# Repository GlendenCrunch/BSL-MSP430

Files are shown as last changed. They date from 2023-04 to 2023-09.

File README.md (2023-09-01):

# BSL MSP430 + ftdi-rs232
+ Scheme and PCB of the adapter USB-FTDI to interface RS-232 and bootloader (BSL) for microcontrollers Texas Instrument MSP430
+ Libraries Eagle: SparkFun
+ For MAX232CPE from China capacitor С6 = 48 uF, otherwise it is not needed
+ Package 3D:

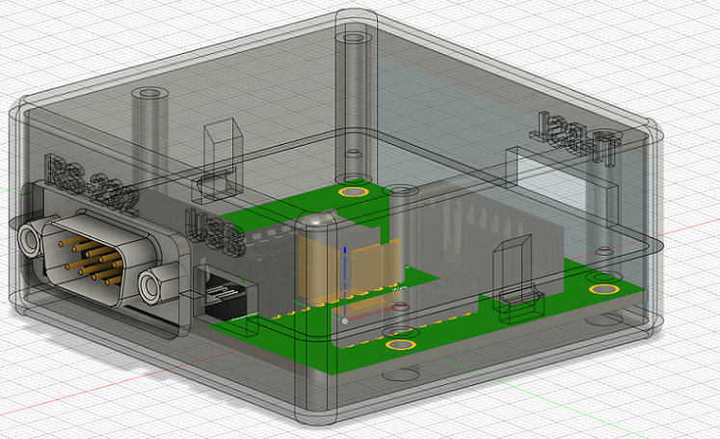
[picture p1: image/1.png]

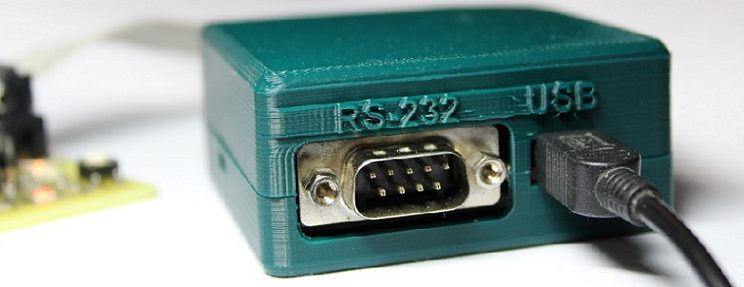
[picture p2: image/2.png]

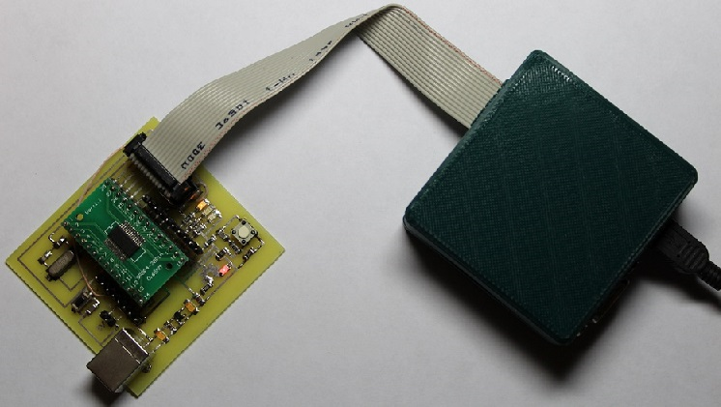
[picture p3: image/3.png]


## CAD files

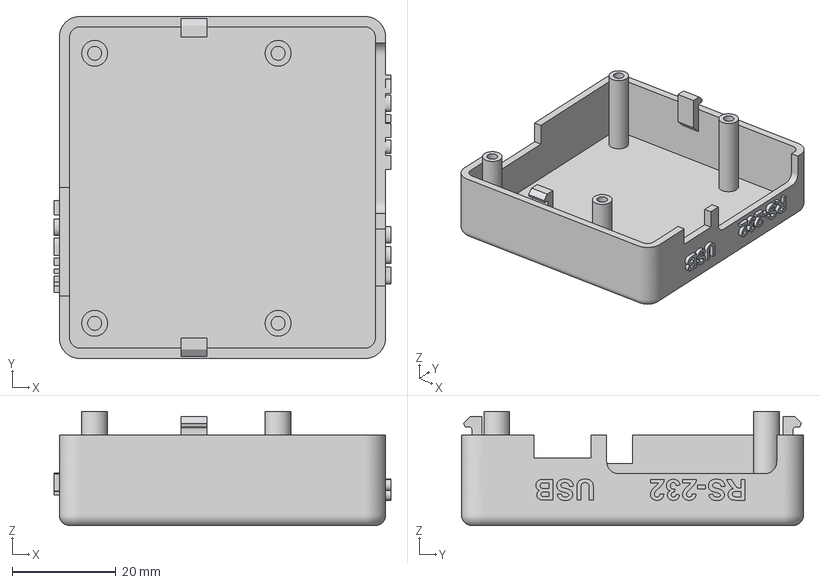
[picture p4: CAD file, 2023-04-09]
case_top.3mf
65.0 x 66.0 x 22.0 mm

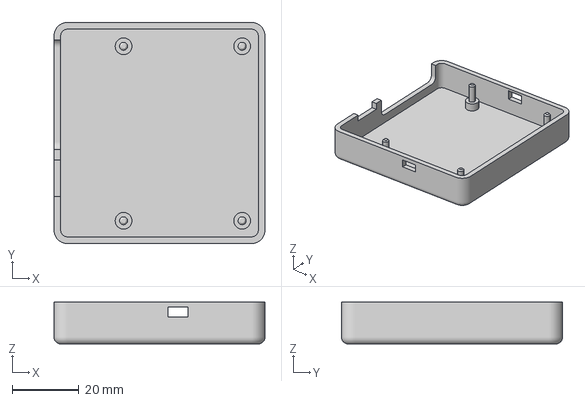
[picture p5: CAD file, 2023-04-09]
case_bottom.3mf
63.0 x 66.0 x 12.5 mm

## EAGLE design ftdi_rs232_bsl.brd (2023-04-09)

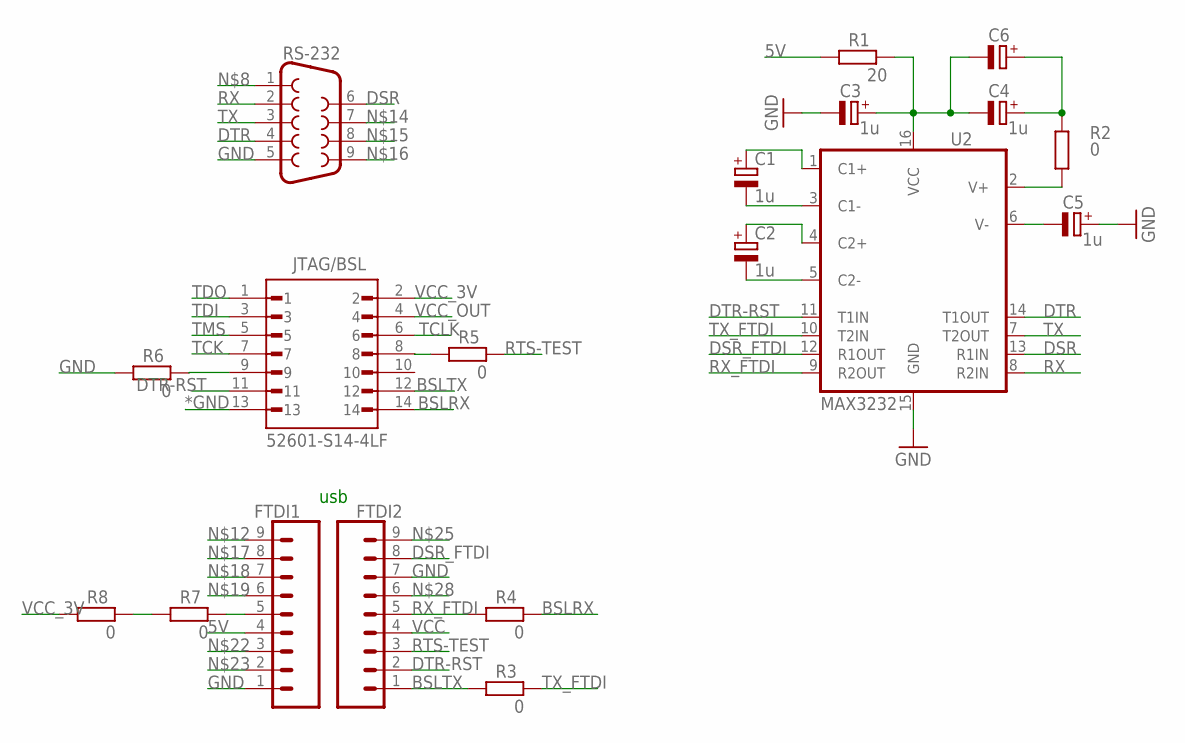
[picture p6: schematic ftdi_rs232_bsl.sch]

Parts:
C1, C2, C3, C4, C5: 1u; B/3528-21W
C6: CPOL-EUB/3528-21W; B/3528-21W
FTDI1, FTDI2: CONN_09NO_SILK; 1X09_NO_SILK
JTAG/BSL: 52601-S14-4LF; AMPHENOL_52601-S14-4LF
R1: 20; R1206
R2, R3, R4, R5, R6, R7, R8: 0; R1206
RS-232: DB9MALE; DB9_MALE
U2: MAX3232; DIP16

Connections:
5V: FTDI1.4, R1.1
*GND: JTAG/BSL.13
BSLRX: JTAG/BSL.14, R4.2
BSLTX: FTDI2.1, JTAG/BSL.12, R3.1
DSR: RS-232.6, U2.13 (R1IN)
DSR_FTDI: FTDI2.8, U2.12 (R1OUT)
DTR: RS-232.4, U2.14 (T1OUT)
DTR-RST: FTDI2.2, JTAG/BSL.11, U2.11 (T1IN)
GND: C3.-, C5.+, FTDI1.1, FTDI2.7, R6.1, RS-232.5, U2.15 (GND)
unnamed: C1.-, U2.3 (C1-)
unnamed: C2.-, U2.5 (C2-)
unnamed: C1.+, U2.1 (C1+)
unnamed: C2.+, U2.4 (C2+)
unnamed: C3.+, C4.-, C6.-, R1.2, U2.16 (VCC)
unnamed: C5.-, U2.6 (V-)
unnamed: C4.+, C6.+, R2.2
unnamed: R2.1, U2.2 (V+)
unnamed: JTAG/BSL.8, R5.1
unnamed: JTAG/BSL.9, R6.2
unnamed: FTDI1.5, R7.2
unnamed: R7.1, R8.2
RTS-TEST: FTDI2.3, R5.2
RX: RS-232.2, U2.8 (R2IN)
RX_FTDI: FTDI2.5, R4.1, U2.9 (R2OUT)
TCK: JTAG/BSL.7
TCLK: JTAG/BSL.6
TDI: JTAG/BSL.3
TDO: JTAG/BSL.1
TMS: JTAG/BSL.5
TX: RS-232.3, U2.7 (T2OUT)
TX_FTDI: R3.2, U2.10 (T2IN)
VCC: FTDI2.4
VCC_3V: JTAG/BSL.2, R8.1
VCC_OUT: JTAG/BSL.4

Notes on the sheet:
usb

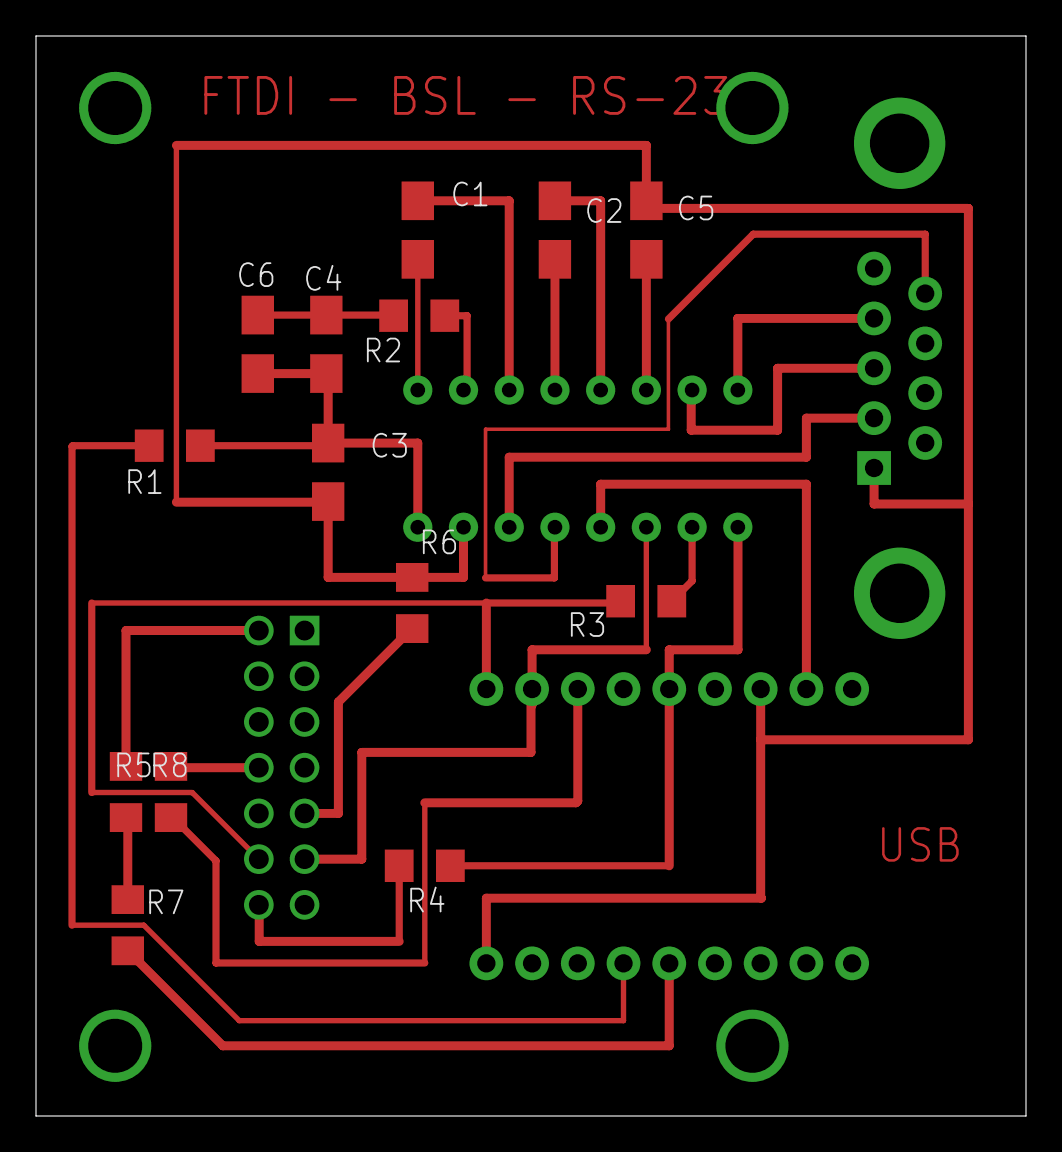
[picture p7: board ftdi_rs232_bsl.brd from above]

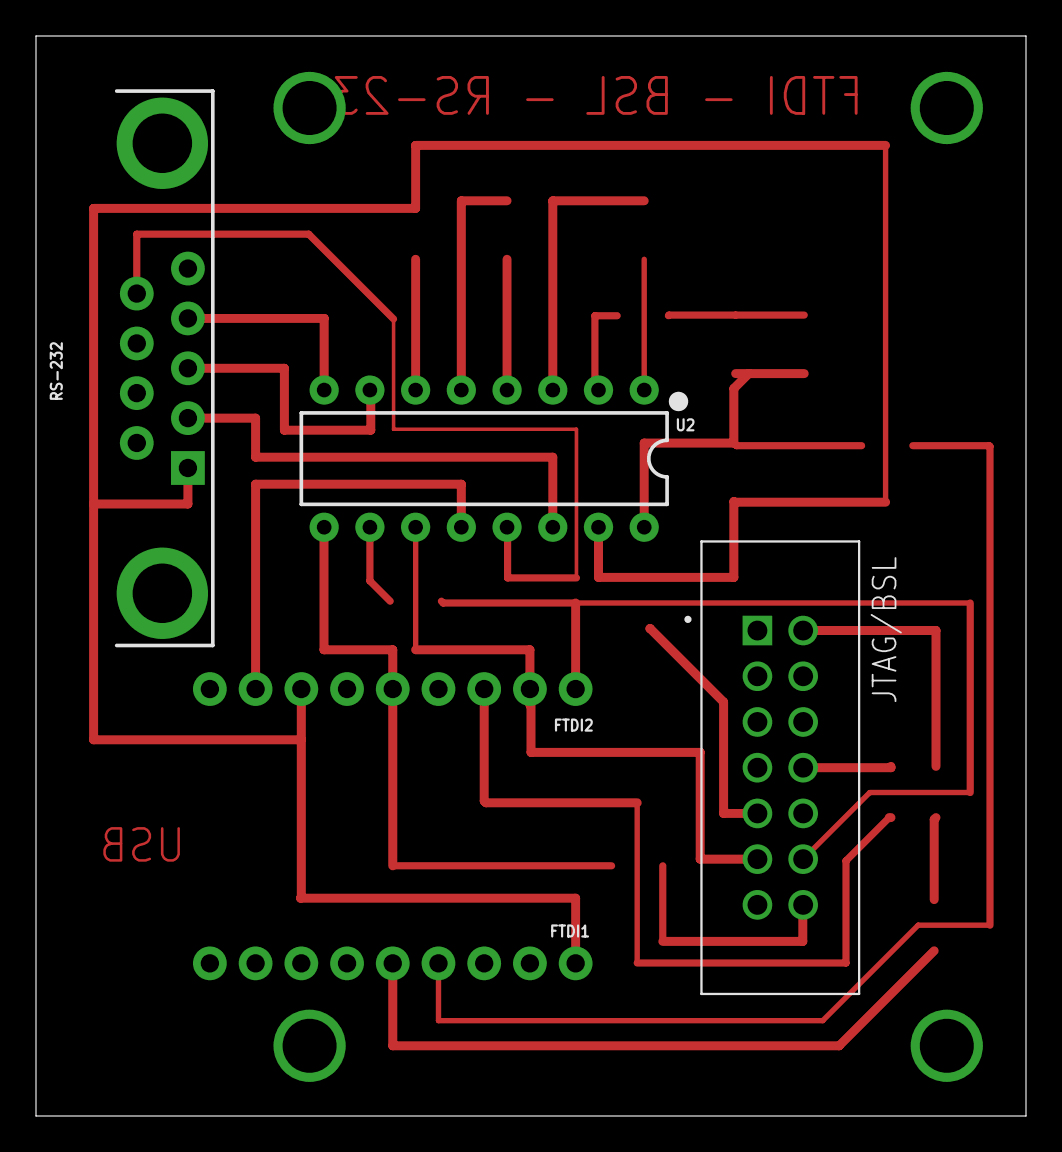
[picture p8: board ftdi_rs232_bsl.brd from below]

Board: 2 copper layers, 55.0 x 60.0 mm, 19 parts (5 on the bottom side), 26 nets.

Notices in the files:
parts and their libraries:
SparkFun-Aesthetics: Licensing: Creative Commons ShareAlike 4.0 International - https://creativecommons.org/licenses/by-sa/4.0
